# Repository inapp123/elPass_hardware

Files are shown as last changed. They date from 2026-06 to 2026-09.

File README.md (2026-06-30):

# ePass EL or elPass

**An open-source EL display controller built on the Xilinx Zynq-7010.**

ePass EL drives an electroluminescent (EL) panel from a Zynq-7010 SoC, pairing
PS-side Linux with PL-side panel timing so you get a real compositor on top of a
display technology that usually only sees bit-banged microcontroller drivers.
HDMI in/out, WiFi/BT, USB host, a resistive touchscreen, and USB-C PD power all
live on a single self-designed four-layer board.

> Rhodes Island Engineering Dept. (c) 1097 — *because every ruler needs a screen.*

---

## Status

| Subsystem | State |
| --- | --- |
| PCB (4-layer) | **Fabricated and bring-up tested.** Working hardware. |
| FPGA / Linux | Architecture defined; EL driver + DRM compositor in progress |
| Enclosure | 2-piece FDM/resin shell, parametric (build123d), in design |

This is `Rev 1`. KiCad 10.0.3 source, schematic dated 2026-05-25.

PCB is designed for JLC04016-3313 stack.1.6mm,3313 imdepend matching.

---

## Highlights

- **Zynq-7010 (CLG400)** — dual-core Cortex-A9 PS + Artix-class PL on one die.
- **EL panel driver in the PL** — column/row drive (`UD*`/`LD*`/`CP*`/`S`) with
  1-bit temporal dithering, level-shifted to the panel through dual TXS0108E.
- **DRM/KMS on Linux** — a single-master compositor owns the CRTC; clients hand
  in buffers over dmabuf. Legacy fbdev programs and even an X server can run as
  clients without ever touching the real DRM master.
- **HDMI, both directions** — J2 is a dual-mode sink/source. Default build is a
  sink (TMDS receive into HR banks via IDELAY/ISERDES); populate `D2` to flip it
  into a source.
- **WiFi + Bluetooth** — RTL8723BS over SDIO (routed through EMIO to the PL),
  with a 2.4 GHz chip antenna and a proper RF keepout.
- **USB-C PD power** — CH224K negotiates 12 V for the panel rail; data lines
  stay free for whatever you want.
- **USB 2.0 host** — USB3320 ULPI PHY (24 MHz) to a full-size Type-A port.
- **Resistive touch** — XPT2046 over SPI.
- **microSD** boot + storage, RTC-less but with the usual JTAG/UART debug paths.

---

## Architecture

```mermaid
flowchart TB
    USBC[USB-C In<br/>CH224K PD sink] --> PWR
    PWR[EA3059 quad buck<br/>+ TPS563201] -->|1V0 / 1V8 / 1V35 / 3V3 / 5V / 12V| ZYNQ

    subgraph ZYNQ[Zynq-7010]
        PS[PS<br/>Cortex-A9 + Linux]
        PL[PL<br/>EL timing + dither<br/>HDMI TMDS]
    end

    PS <-->|EMIO SDIO| WIFI[RTL8723BS<br/>WiFi/BT]
    PS --> USB[USB3320 ULPI] --> USBA[USB-A Host]
    PS --> SD[microSD]
    PS <-->|DDR| DDR[MT41K256M16<br/>512 MB DDR3L]

    PL -->|level shift| EL[EL Panel]
    PL <--> HDMI[HDMI A<br/>sink / source]
    PS -->|SPI| TOUCH[XPT2046<br/>resistive touch]
```

### PS / PL split

- **PS** runs Linux and owns the slow-and-smart side: USB, SD, the RTL8723BS
  (SDIO bridged out through EMIO to PL pins), DDR3L, and the touch SPI link.
- **PL** owns the timing-critical side: generating EL panel drive waveforms with
  1-bit dithering, and the HDMI TMDS datapath.

---

## Power tree

USB-C comes in, CH224K trips the source to **12 V**, and everything fans out from
there. The Zynq rails are brought up in the order the datasheet asks for.

| Rail | Source | Notes |
| --- | --- | --- |
| +5 V | TPS563201 | Buck from VBUS |
| +1.0 V | EA3059 | `VCCINT` / `VCCPINT` |
| +1.8 V | EA3059 | `VCCAUX` / `VCCPAUX` / MIO bank 1 |
| +1.35 V| EA3059 | DDR3L `VCCO_DDR` |
| +3.3 V | EA3059 | I/O banks, MIO bank 0, last to rise |

**Sequence:** `1.0 V → 1.8 V → 1.35 V → 3.3 V`
(approx. instant → 22 ms → 41 ms → 55 ms, set by the enable-cap timing).
A **MAX811** supervises the last-rising 3.3 V rail and drives `PS_POR_B`.

**Panel budget:** 5 V @ 300 mA max, 12 V @ 1.3 A max.

---

## Boot configuration

Mode straps live on the MIO pins (see `zynq_misc`):

| Pins | Value | Meaning |
| --- | --- | --- |
| MIO[6] | `0` | Wait for PLL lock, then run BootROM |
| MIO[8:7]  | `2'b10` | 3.3 V on both MIO banks |
| MIO[5:3]  | `3'b110` | Boot from SD card |
| MIO[2] | `0` | JTAG chain: cascaded |

PS reference clock is a 50 MHz oscillator. JTAG is broken out on a ZX-SH1.0
header for bring-up.

---

## Software stack

The interesting part isn't that it runs Linux — it's *how the display is shared.*

- **Single-master DRM compositor.** A DRM lease can't split a CRTC between two
  masters, so one compositor owns all atomic commits. Clients submit buffers as
  dmabuf file descriptors passed over a Unix socket (`SCM_RIGHTS`).
- **Legacy fbdev support** via `LD_PRELOAD`, intercepting `open`/`ioctl`/`mmap`
  so old framebuffer programs think they own a screen.
- **X11 as a client** — `xf86-video-fbdev` runs against the compositor's virtual
  framebuffer, keeping the compositor as the sole DRM master.
- **Touch routing.** The real input device is grabbed (`EVIOCGRAB`) and a virtual
  device is published via `uinput`/`libevdev`; the compositor routes events by
  overlay visibility. On focus switch, in-flight multitouch slots are cancelled
  cleanly (`ABS_MT_TRACKING_ID = -1`, `BTN_TOUCH = 0`, `SYN_REPORT`). A udev rule
  (`LIBINPUT_IGNORE_DEVICE=1`) hides the raw device from X's libinput.

## Credits

This design stands on the shoulders of:

- **ZYNQ_Ruler** by Stanlazy — <https://github.com/Stanlazy/ZYNQ_Ruler>
- **Enchanter** by Modos Tech / Wenting Zhang
- **EBAZ4205** community reverse-engineering work

Thanks to everyone who documented Zynq-7010 minimal designs and EL driving so the
rest of us didn't have to start from a blank schematic.

---

## License

CERN-OHL-P.

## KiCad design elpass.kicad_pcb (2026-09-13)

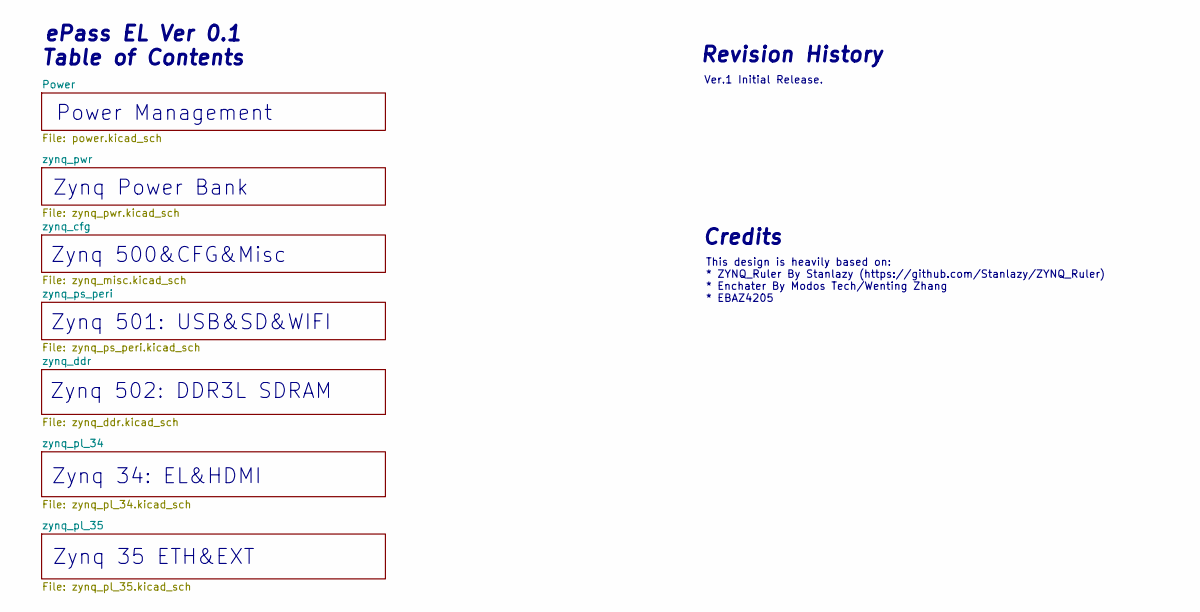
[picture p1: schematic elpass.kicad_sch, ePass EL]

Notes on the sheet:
Zynq Power Bank
Zynq 502: DDR3L SDRAM
Zynq 35 ETH&EXT
ePass EL Ver 0.1 Table of Contents
Power Management
Credits
Zynq 500&CFG&Misc
Zynq 34: EL&HDMI
Ver.1 Initial Release.
Zynq 501: USB&SD&WIFI
This design is heavily based on: * ZYNQ_Ruler By Stanlazy (https://github.com/Stanlazy/ZYNQ_Ruler) * Enchater By Modos Tech/Wenting Zhang * EBAZ4205
Revision History

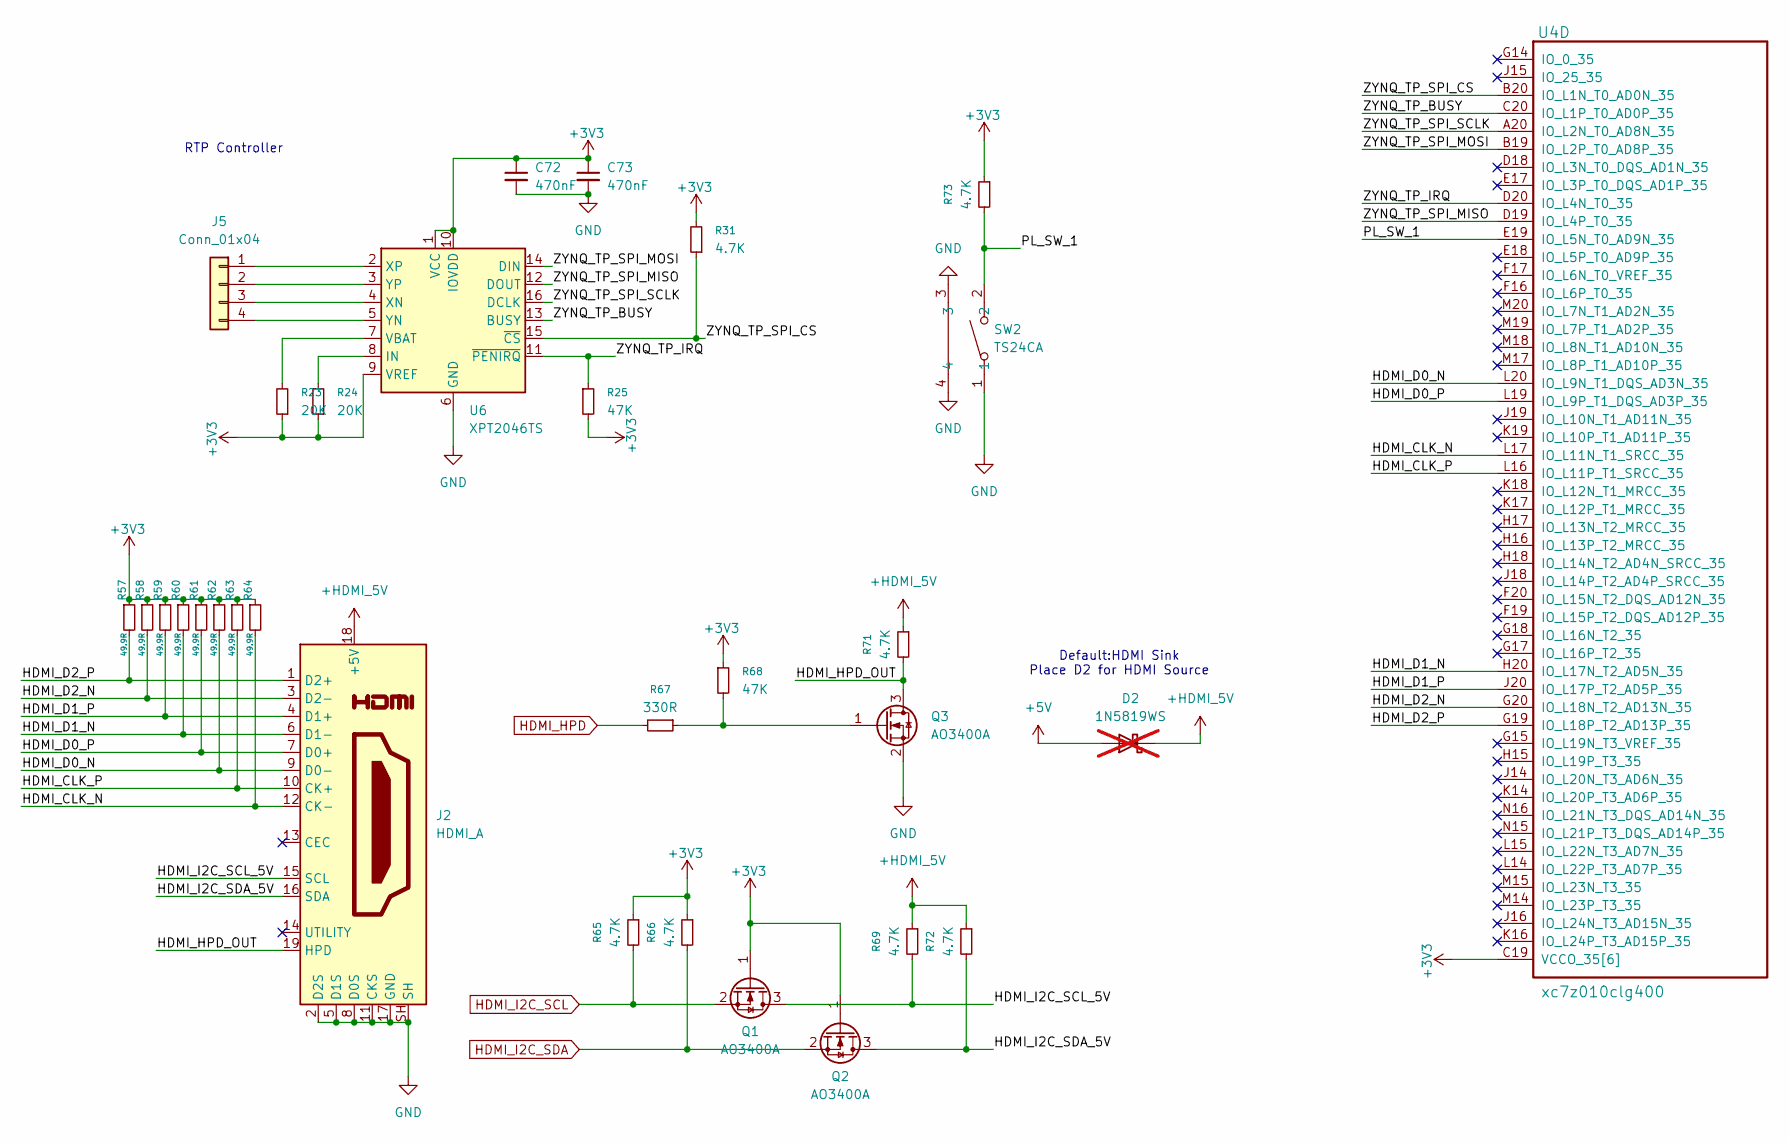
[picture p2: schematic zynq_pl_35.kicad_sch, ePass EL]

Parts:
C72, C73: 470nF; C_0201_0603Metric
D2: 1N5819WS; D_SOD-323; not fitted
J2: HDMI_A; HDMI_A_Molex_208658-1001_Horizontal
J5: Conn_01x04; PinHeader_1x04_P2.54mm_Horizontal
Q1, Q2, Q3: AO3400A; SOT-23
R23, R24: 20K; R_0402_1005Metric
R25, R68: 47K; R_0402_1005Metric
R31, R65, R66, R69, R71, R72, R73: 4.7K; R_0402_1005Metric
R57, R58, R59, R60, R61, R62, R63, R64: 49.9R; R_0402_1005Metric
R67: 330R; R_0402_1005Metric
SW2: TS24CA; SW-SMD_2P-TS24CA; MPN TS24CA; LCSC Part C393942
U4: xc7z010clg400; Xilinx_CLG400_NoPaste_JLC_Package_Delay
U6: XPT2046TS; TSSOP-16_4.4x5mm_P0.65mm

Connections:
+3V3: C72.1, C73.1, Q1.1 (G), Q2.1 (G), R23.1, R24.1, R25.2, R31.2, R57.1, R58.1, R59.1, R60.1, R61.1, R62.1, R63.1, R64.1, R65.1, R66.1, R68.1, R73.1, U4.C19 (VCCO_35[6]), U4.F18 (VCCO_35[6]), U4.H14 (VCCO_35[6]), U4.J17 (VCCO_35[6]), U4.K20 (VCCO_35[6]), U4.M16 (VCCO_35[6]), U6.1 (VCC), U6.9 (VREF), U6.10 (IOVDD); also elsewhere on the board
+5V: D2.2 (A); also elsewhere on the board
+HDMI_5V: D2.1 (K), J2.18 (+5V), R69.1, R71.1, R72.1
/zynq_pl_35/HDMI_CLK_N: J2.12 (CK-), R64.2, U4.L17 (IO_L11N_T1_SRCC_35)
/zynq_pl_35/HDMI_CLK_P: J2.10 (CK+), R63.2, U4.L16 (IO_L11P_T1_SRCC_35)
/zynq_pl_35/HDMI_D0_N: J2.9 (D0-), R62.2, U4.L20 (IO_L9N_T1_DQS_AD3N_35)
/zynq_pl_35/HDMI_D0_P: J2.7 (D0+), R61.2, U4.L19 (IO_L9P_T1_DQS_AD3P_35)
/zynq_pl_35/HDMI_D1_N: J2.6 (D1-), R60.2, U4.H20 (IO_L17N_T2_AD5N_35)
/zynq_pl_35/HDMI_D1_P: J2.4 (D1+), R59.2, U4.J20 (IO_L17P_T2_AD5P_35)
/zynq_pl_35/HDMI_D2_N: J2.3 (D2-), R58.2, U4.G20 (IO_L18N_T2_AD13N_35)
/zynq_pl_35/HDMI_D2_P: J2.1 (D2+), R57.2, U4.G19 (IO_L18P_T2_AD13P_35)
/zynq_pl_35/HDMI_HPD_OUT: J2.19 (HPD), Q3.3 (D), R71.2
/zynq_pl_35/HDMI_I2C_SCL_5V: J2.15 (SCL), Q1.3 (D), R69.2
/zynq_pl_35/HDMI_I2C_SDA_5V: J2.16 (SDA), Q2.3 (D), R72.2
/zynq_pl_35/PL_SW_1: R73.2, SW2.2, U4.E19 (IO_L5N_T0_AD9N_35)
/zynq_pl_35/ZYNQ_TP_BUSY: U4.C20 (IO_L1P_T0_AD0P_35), U6.13 (BUSY)
/zynq_pl_35/ZYNQ_TP_IRQ: R25.1, U4.D20 (IO_L4N_T0_35), U6.11 (~PENIRQ)
/zynq_pl_35/ZYNQ_TP_SPI_CS: R31.1, U4.B20 (IO_L1N_T0_AD0N_35), U6.15 (~CS)
/zynq_pl_35/ZYNQ_TP_SPI_MISO: U4.D19 (IO_L4P_T0_35), U6.12 (DOUT)
/zynq_pl_35/ZYNQ_TP_SPI_MOSI: U4.B19 (IO_L2P_T0_AD8P_35), U6.14 (DIN)
/zynq_pl_35/ZYNQ_TP_SPI_SCLK: U4.A20 (IO_L2N_T0_AD8N_35), U6.16 (DCLK)
GND: C72.2, C73.2, J2.2 (D2S), J2.5 (D1S), J2.8 (D0S), J2.11 (CKS), J2.17 (GND), J2.SH, Q3.2 (S), SW2.1, SW2.3, SW2.4, U6.6 (GND); also elsewhere on the board
HDMI_HPD: R67.2; also elsewhere on the board
HDMI_I2C_SCL: Q1.2 (S), R65.2; also elsewhere on the board
HDMI_I2C_SDA: Q2.2 (S), R66.2; also elsewhere on the board
unnamed: J5.1, U6.2 (XP)
unnamed: J5.2, U6.3 (YP)
unnamed: J5.3, U6.4 (XN)
unnamed: J5.4, U6.5 (YN)
unnamed: Q3.1 (G), R67.1, R68.2
unnamed: R24.2, U6.8 (IN)
unnamed: R23.2, U6.7 (VBAT)

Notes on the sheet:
Default:HDMI Sink Place D2 for HDMI Source
RTP Controller

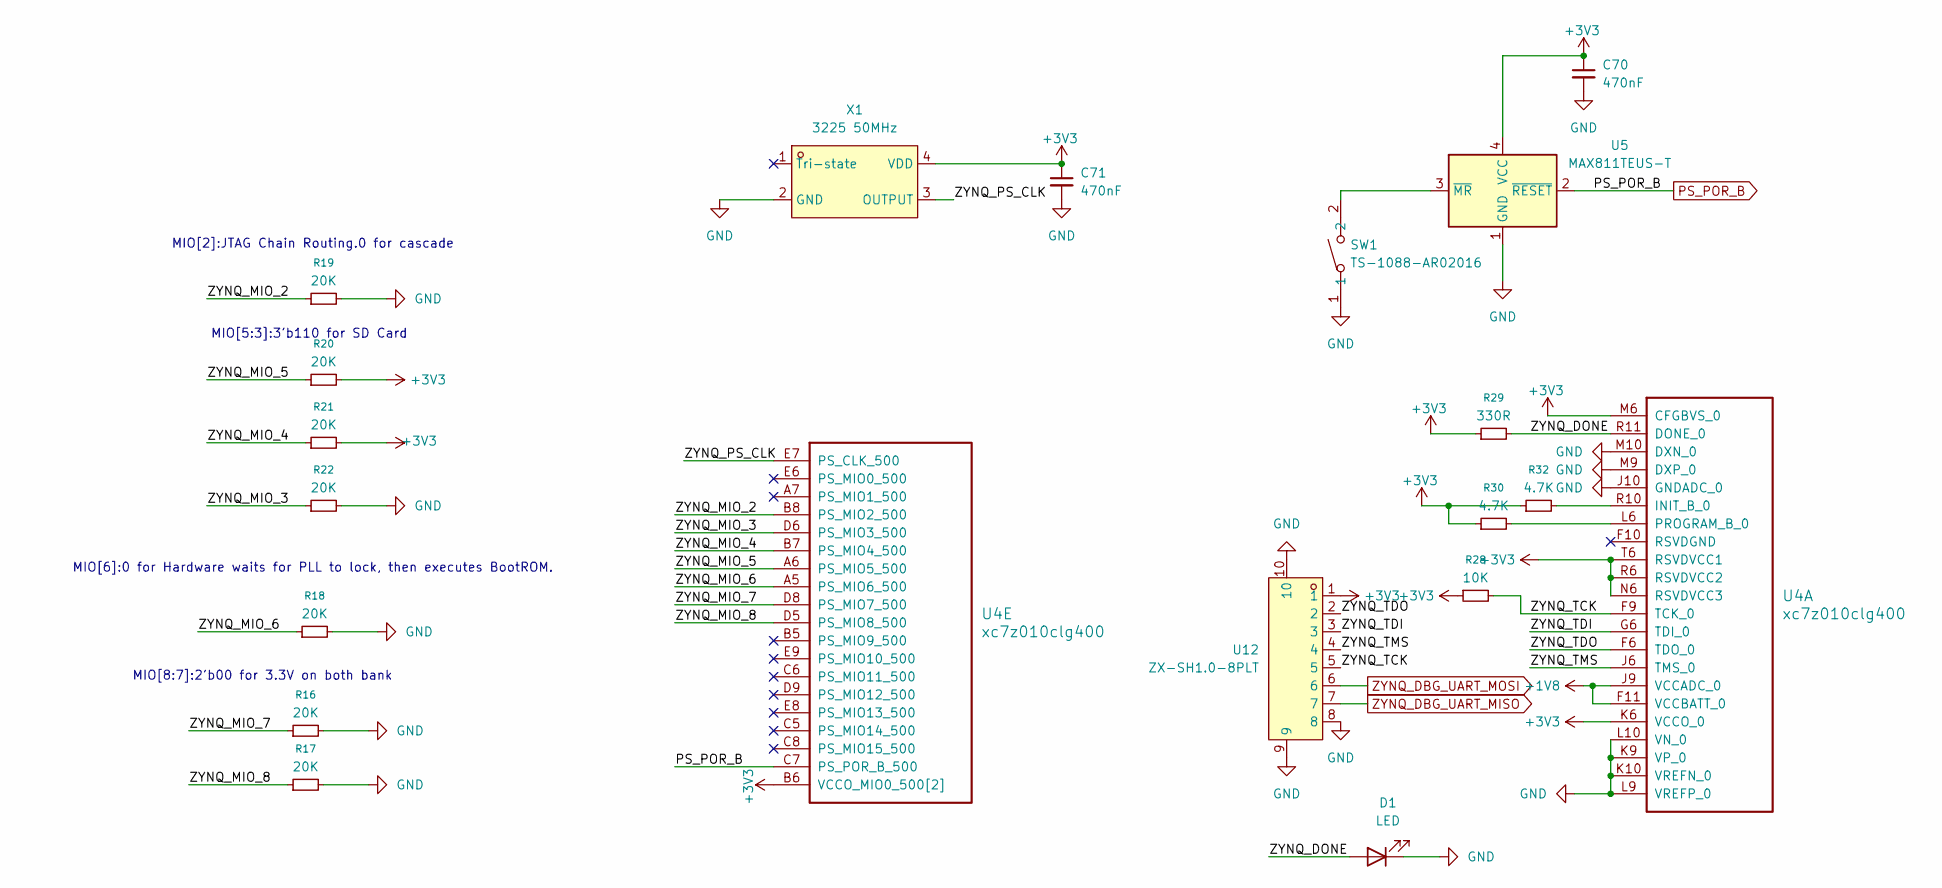
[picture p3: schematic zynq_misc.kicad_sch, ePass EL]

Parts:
C70, C71: 470nF; C_0201_0603Metric
D1: LED; LED_0603_1608Metric
R16, R17, R18, R19, R20, R21, R22: 20K; R_0402_1005Metric
R28: 10K; R_0402_1005Metric
R29: 330R; R_0402_1005Metric
R30, R32: 4.7K; R_0402_1005Metric
SW1: TS-1088-AR02016; SW-SMD_L3.9-W3.0-P4.45; MPN TS-1088-AR02016; LCSC Part C720477
U4: xc7z010clg400; Xilinx_CLG400_NoPaste_JLC_Package_Delay
U5: MAX811TEUS-T; SOT-143
U12: ZX-SH1.0-8PLT; CONN-SMD_8P-P1.00_MEGASTAR_ZX-SH1.0-8PLT; MPN ZX-SH1.0-8PLT; LCSC Part C7430457
X1: 3225 50MHz; OSC-SMD_4P-L3.2-W2.5-BL; MPN OT322550MJBA4SL; LCSC Part C717684

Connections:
+1V8: U4.F11 (VCCBATT_0), U4.J9 (VCCADC_0); also elsewhere on the board
+3V3: C70.1, C71.1, R20.2, R21.2, R28.1, R29.1, R30.1, R32.1, U4.B6 (VCCO_MIO0_500[2]), U4.D7 (VCCO_MIO0_500[2]), U4.K6 (VCCO_0), U4.M6 (CFGBVS_0), U4.N6 (RSVDVCC3), U4.R6 (RSVDVCC2), U4.T6 (RSVDVCC1), U5.4 (VCC), U12.1, X1.4 (VDD); also elsewhere on the board
/zynq_cfg/ZYNQ_DONE: D1.2 (A), R29.2, U4.R11 (DONE_0)
/zynq_cfg/ZYNQ_MIO_2: R19.1, U4.B8 (PS_MIO2_500)
/zynq_cfg/ZYNQ_MIO_3: R22.1, U4.D6 (PS_MIO3_500)
/zynq_cfg/ZYNQ_MIO_4: R21.1, U4.B7 (PS_MIO4_500)
/zynq_cfg/ZYNQ_MIO_5: R20.1, U4.A6 (PS_MIO5_500)
/zynq_cfg/ZYNQ_MIO_6: R18.1, U4.A5 (PS_MIO6_500)
/zynq_cfg/ZYNQ_MIO_7: R16.1, U4.D8 (PS_MIO7_500)
/zynq_cfg/ZYNQ_MIO_8: R17.1, U4.D5 (PS_MIO8_500)
/zynq_cfg/ZYNQ_PS_CLK: U4.E7 (PS_CLK_500), X1.3 (OUTPUT)
/zynq_cfg/ZYNQ_TCK: R28.2, U4.F9 (TCK_0), U12.5
/zynq_cfg/ZYNQ_TDI: U4.G6 (TDI_0), U12.3
/zynq_cfg/ZYNQ_TDO: U4.F6 (TDO_0), U12.2
/zynq_cfg/ZYNQ_TMS: U4.J6 (TMS_0), U12.4
GND: C70.2, C71.2, D1.1 (K), R16.2, R17.2, R18.2, R19.2, R22.2, SW1.1, U4.J10 (GNDADC_0), U4.K9 (VP_0), U4.K10 (VREFN_0), U4.L9 (VREFP_0), U4.L10 (VN_0), U4.M9 (DXP_0), U4.M10 (DXN_0), U5.1 (GND), U12.8, U12.9, U12.10, X1.2 (GND); also elsewhere on the board
unnamed: R32.2, U4.R10 (INIT_B_0)
unnamed: R30.2, U4.L6 (PROGRAM_B_0)
unnamed: SW1.2, U5.3 (~MR)
PS_POR_B: U4.C7 (PS_POR_B_500), U5.2 (~RESET)
ZYNQ_DBG_UART_MISO: U12.7; also elsewhere on the board
ZYNQ_DBG_UART_MOSI: U12.6; also elsewhere on the board

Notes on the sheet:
MIO[5:3]:3'b110 for SD Card
MIO[8:7]:2'b00 for 3.3V on both bank
MIO[2]:JTAG Chain Routing.0 for cascade
MIO[6]:0 for Hardware waits for PLL to lock, then executes BootROM.

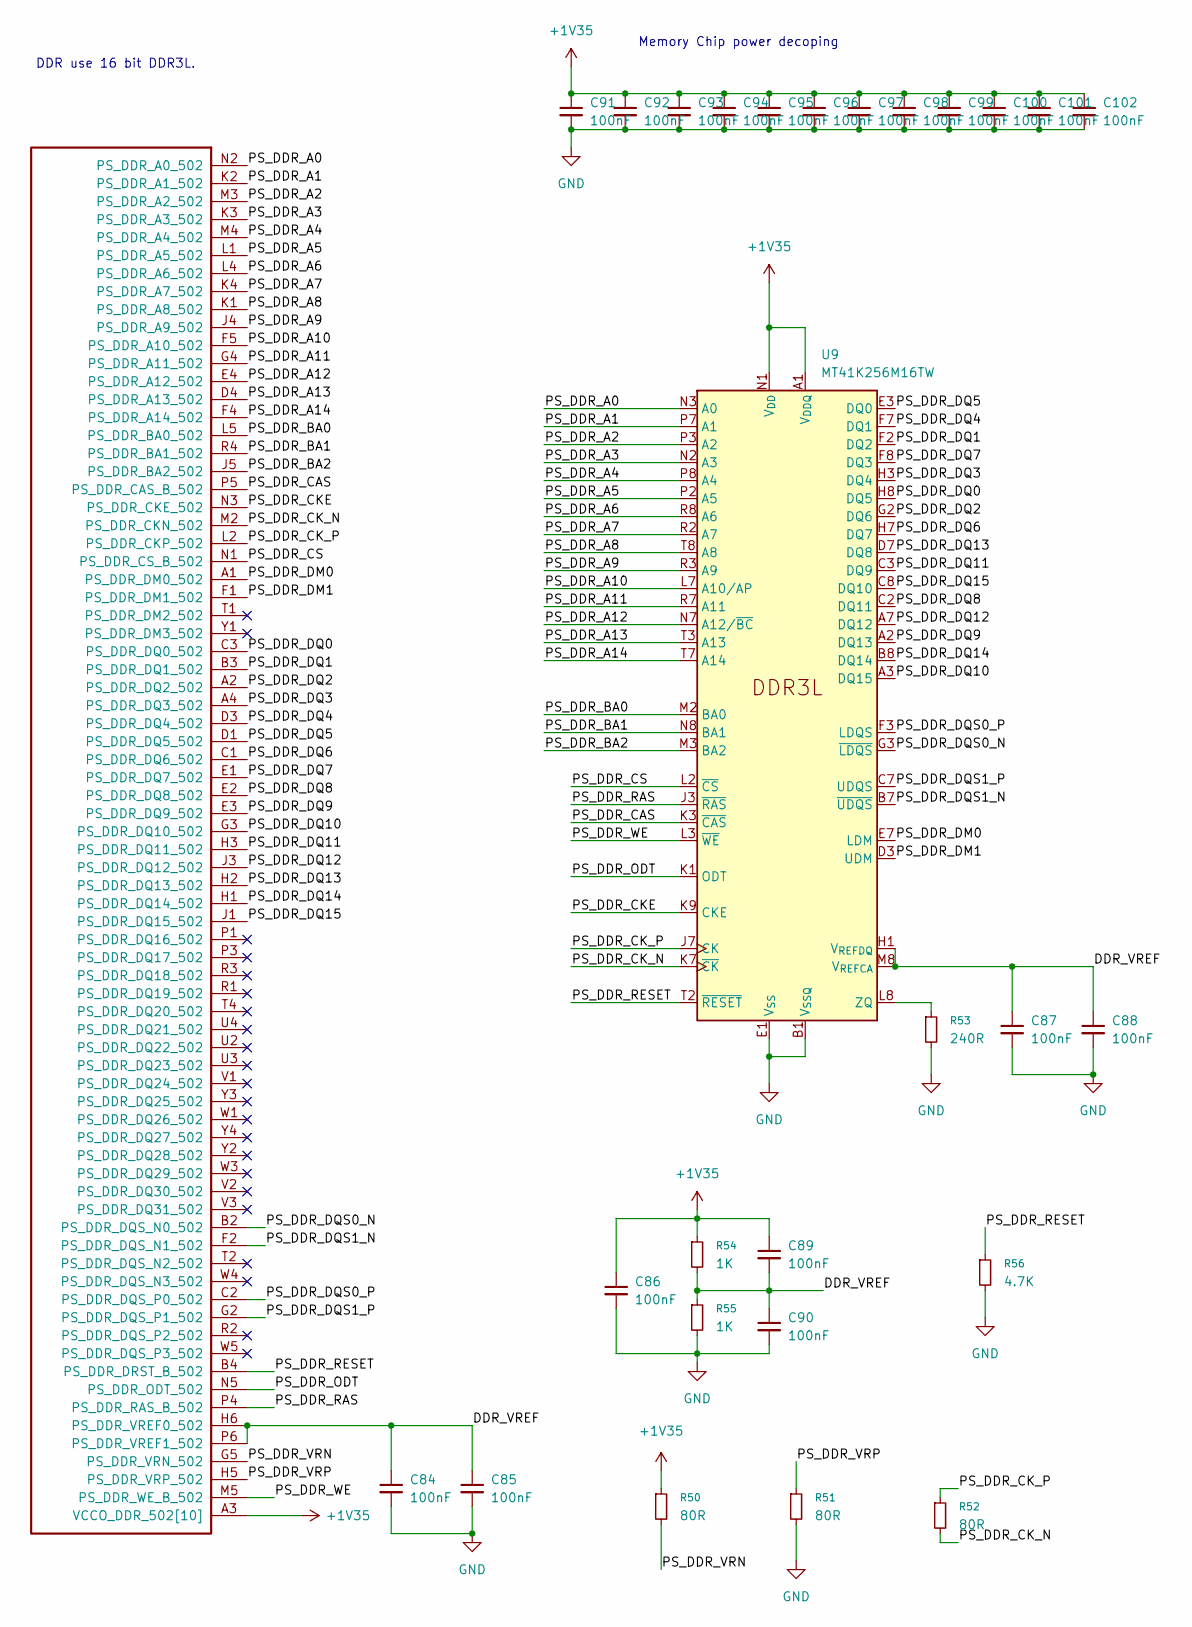
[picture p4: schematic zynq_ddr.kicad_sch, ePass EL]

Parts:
C84, C86, C87, C88, C89, C90, C91, C92, C93, C94, C95, C98, C99, C100, C101, C102: 100nF; C_0201_0603Metric
C85, C96, C97: 100nF; C_0201_0603Metric_WideGap
R50, R51: 80R; R_0201_0603Metric
R52: 80R; C_0201_0603Metric_WideGap
R53: 240R; R_0201_0603Metric
R54, R55: 1K; R_0402_1005Metric
R56: 4.7K; R_0402_1005Metric
U4: xc7z010clg400; Xilinx_CLG400_NoPaste_JLC_Package_Delay
U9: MT41K256M16TW; BGA-96_P0.8mm_NoPaste

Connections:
+1V35: C86.1, C89.1, C91.1, C92.1, C93.1, C94.1, C95.1, C96.1, C97.1, C98.1, C99.1, C100.1, C101.1, C102.1, R50.1, R54.1, U4.A3 (VCCO_DDR_502[10]), U4.D2 (VCCO_DDR_502[10]), U4.E5 (VCCO_DDR_502[10]), U4.G1 (VCCO_DDR_502[10]), U4.H4 (VCCO_DDR_502[10]), U4.L3 (VCCO_DDR_502[10]), U4.P2 (VCCO_DDR_502[10]), U4.R5 (VCCO_DDR_502[10]), U4.U1 (VCCO_DDR_502[10]), U4.V4 (VCCO_DDR_502[10]), U9.A1 (V_{DDQ}), U9.A8 (V_{DDQ}), U9.B2 (V_{DD}), U9.C1 (V_{DDQ}), U9.C9 (V_{DDQ}), U9.D2 (V_{DDQ}), U9.D9 (V_{DD}), U9.E9 (V_{DDQ}), U9.F1 (V_{DDQ}), U9.G7 (V_{DD}), U9.H2 (V_{DDQ}), U9.H9 (V_{DDQ}), U9.K2 (V_{DD}), U9.K8 (V_{DD}), U9.N1 (V_{DD}), U9.N9 (V_{DD}), U9.R1 (V_{DD}), U9.R9 (V_{DD}); also elsewhere on the board
/zynq_ddr/DDR_VREF: C84.1, C85.1, C87.1, C88.1, C89.2, C90.1, R54.2, R55.1, U4.H6 (PS_DDR_VREF0_502), U4.P6 (PS_DDR_VREF1_502), U9.H1 (V_{REFDQ}), U9.M8 (V_{REFCA})
/zynq_ddr/PS_DDR_A0: U4.N2 (PS_DDR_A0_502), U9.N3 (A0)
/zynq_ddr/PS_DDR_A1: U4.K2 (PS_DDR_A1_502), U9.P7 (A1)
/zynq_ddr/PS_DDR_A2: U4.M3 (PS_DDR_A2_502), U9.P3 (A2)
/zynq_ddr/PS_DDR_A3: U4.K3 (PS_DDR_A3_502), U9.N2 (A3)
/zynq_ddr/PS_DDR_A4: U4.M4 (PS_DDR_A4_502), U9.P8 (A4)
/zynq_ddr/PS_DDR_A5: U4.L1 (PS_DDR_A5_502), U9.P2 (A5)
/zynq_ddr/PS_DDR_A6: U4.L4 (PS_DDR_A6_502), U9.R8 (A6)
/zynq_ddr/PS_DDR_A7: U4.K4 (PS_DDR_A7_502), U9.R2 (A7)
/zynq_ddr/PS_DDR_A8: U4.K1 (PS_DDR_A8_502), U9.T8 (A8)
/zynq_ddr/PS_DDR_A9: U4.J4 (PS_DDR_A9_502), U9.R3 (A9)
/zynq_ddr/PS_DDR_A10: U4.F5 (PS_DDR_A10_502), U9.L7 (A10/AP)
/zynq_ddr/PS_DDR_A11: U4.G4 (PS_DDR_A11_502), U9.R7 (A11)
/zynq_ddr/PS_DDR_A12: U4.E4 (PS_DDR_A12_502), U9.N7 (A12/~BC)
/zynq_ddr/PS_DDR_A13: U4.D4 (PS_DDR_A13_502), U9.T3 (A13)
/zynq_ddr/PS_DDR_A14: U4.F4 (PS_DDR_A14_502), U9.T7 (A14)
/zynq_ddr/PS_DDR_BA0: U4.L5 (PS_DDR_BA0_502), U9.M2 (BA0)
/zynq_ddr/PS_DDR_BA1: U4.R4 (PS_DDR_BA1_502), U9.N8 (BA1)
/zynq_ddr/PS_DDR_BA2: U4.J5 (PS_DDR_BA2_502), U9.M3 (BA2)
/zynq_ddr/PS_DDR_CAS: U4.P5 (PS_DDR_CAS_B_502), U9.K3 (~CAS)
/zynq_ddr/PS_DDR_CKE: U4.N3 (PS_DDR_CKE_502), U9.K9 (CKE)
/zynq_ddr/PS_DDR_CK_N: R52.2, U4.M2 (PS_DDR_CKN_502), U9.K7 (~CK)
/zynq_ddr/PS_DDR_CK_P: R52.1, U4.L2 (PS_DDR_CKP_502), U9.J7 (CK)
/zynq_ddr/PS_DDR_CS: U4.N1 (PS_DDR_CS_B_502), U9.L2 (~CS)
/zynq_ddr/PS_DDR_DM0: U4.A1 (PS_DDR_DM0_502), U9.E7 (LDM)
/zynq_ddr/PS_DDR_DM1: U4.F1 (PS_DDR_DM1_502), U9.D3 (UDM)
/zynq_ddr/PS_DDR_DQ0: U4.C3 (PS_DDR_DQ0_502), U9.H8 (DQ5)
/zynq_ddr/PS_DDR_DQ1: U4.B3 (PS_DDR_DQ1_502), U9.F2 (DQ2)
/zynq_ddr/PS_DDR_DQ2: U4.A2 (PS_DDR_DQ2_502), U9.G2 (DQ6)
/zynq_ddr/PS_DDR_DQ3: U4.A4 (PS_DDR_DQ3_502), U9.H3 (DQ4)
/zynq_ddr/PS_DDR_DQ4: U4.D3 (PS_DDR_DQ4_502), U9.F7 (DQ1)
/zynq_ddr/PS_DDR_DQ5: U4.D1 (PS_DDR_DQ5_502), U9.E3 (DQ0)
/zynq_ddr/PS_DDR_DQ6: U4.C1 (PS_DDR_DQ6_502), U9.H7 (DQ7)
/zynq_ddr/PS_DDR_DQ7: U4.E1 (PS_DDR_DQ7_502), U9.F8 (DQ3)
/zynq_ddr/PS_DDR_DQ8: U4.E2 (PS_DDR_DQ8_502), U9.C2 (DQ11)
/zynq_ddr/PS_DDR_DQ9: U4.E3 (PS_DDR_DQ9_502), U9.A2 (DQ13)
/zynq_ddr/PS_DDR_DQ10: U4.G3 (PS_DDR_DQ10_502), U9.A3 (DQ15)
/zynq_ddr/PS_DDR_DQ11: U4.H3 (PS_DDR_DQ11_502), U9.C3 (DQ9)
/zynq_ddr/PS_DDR_DQ12: U4.J3 (PS_DDR_DQ12_502), U9.A7 (DQ12)
/zynq_ddr/PS_DDR_DQ13: U4.H2 (PS_DDR_DQ13_502), U9.D7 (DQ8)
/zynq_ddr/PS_DDR_DQ14: U4.H1 (PS_DDR_DQ14_502), U9.B8 (DQ14)
/zynq_ddr/PS_DDR_DQ15: U4.J1 (PS_DDR_DQ15_502), U9.C8 (DQ10)
/zynq_ddr/PS_DDR_DQS0_N: U4.B2 (PS_DDR_DQS_N0_502), U9.G3 (~LDQS)
/zynq_ddr/PS_DDR_DQS0_P: U4.C2 (PS_DDR_DQS_P0_502), U9.F3 (LDQS)
/zynq_ddr/PS_DDR_DQS1_N: U4.F2 (PS_DDR_DQS_N1_502), U9.B7 (~UDQS)
/zynq_ddr/PS_DDR_DQS1_P: U4.G2 (PS_DDR_DQS_P1_502), U9.C7 (UDQS)
/zynq_ddr/PS_DDR_ODT: U4.N5 (PS_DDR_ODT_502), U9.K1 (ODT)
/zynq_ddr/PS_DDR_RAS: U4.P4 (PS_DDR_RAS_B_502), U9.J3 (~RAS)
/zynq_ddr/PS_DDR_RESET: R56.1, U4.B4 (PS_DDR_DRST_B_502), U9.T2 (~RESET)
/zynq_ddr/PS_DDR_VRN: R50.2, U4.G5 (PS_DDR_VRN_502)
/zynq_ddr/PS_DDR_VRP: R51.1, U4.H5 (PS_DDR_VRP_502)
/zynq_ddr/PS_DDR_WE: U4.M5 (PS_DDR_WE_B_502), U9.L3 (~WE)
GND: C84.2, C85.2, C86.2, C87.2, C88.2, C90.2, C91.2, C92.2, C93.2, C94.2, C95.2, C96.2, C97.2, C98.2, C99.2, C100.2, C101.2, C102.2, R51.2, R53.2, R55.2, R56.2, U9.A9 (V_{SS}), U9.B1 (V_{SSQ}), U9.B3 (V_{SS}), U9.B9 (V_{SSQ}), U9.D1 (V_{SSQ}), U9.D8 (V_{SSQ}), U9.E1 (V_{SS}), U9.E2 (V_{SSQ}), U9.E8 (V_{SSQ}), U9.F9 (V_{SSQ}), U9.G1 (V_{SSQ}), U9.G8 (V_{SS}), U9.G9 (V_{SSQ}), U9.J2 (V_{SS}), U9.J8 (V_{SS}), U9.M1 (V_{SS}), U9.M9 (V_{SS}), U9.P1 (V_{SS}), U9.P9 (V_{SS}), U9.T1 (V_{SS}), U9.T9 (V_{SS}); also elsewhere on the board
unnamed: R53.1, U9.L8 (ZQ)

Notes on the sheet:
DDR use 16 bit DDR3L.
Memory Chip power decoping

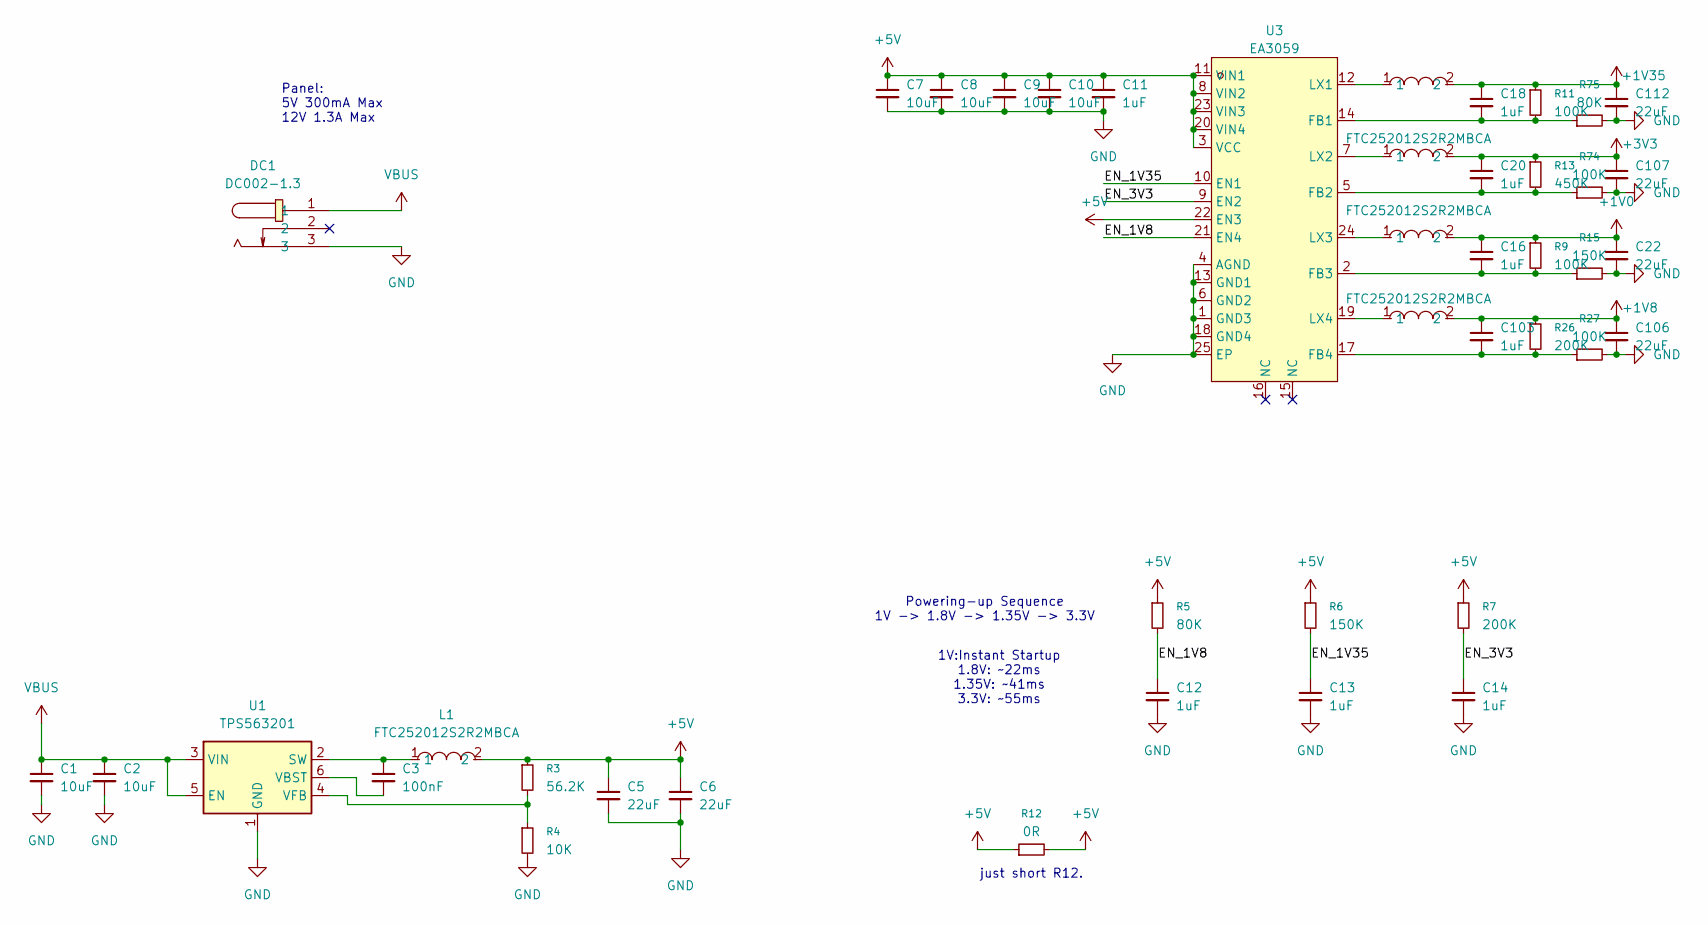
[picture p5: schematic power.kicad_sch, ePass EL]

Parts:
C1, C2, C7, C8, C9, C10: 10uF; C_0805_2012Metric
C3: 100nF; C_0201_0603Metric
C5, C6, C22, C106, C107, C112: 22uF; C_0603_1608Metric
C11, C12, C13, C14, C16, C18, C20, C103: 1uF; C_0402_1005Metric
DC1: DC002-1.3; DC-IN-TH_DC002-1.3; MPN DC002-1.3; LCSC Part C668593
L1, L3, L5, L6, L8: FTC252012S2R2MBCA; IND-SMD_L2.5-W2.0_MHCHL2520; MPN FTC252012S2R2MBCA; LCSC Part C5832372
R3: 56.2K; R_0402_1005Metric
R4: 10K; R_0402_1005Metric
R5, R75: 80K; R_0402_1005Metric
R6, R15: 150K; R_0402_1005Metric
R7, R26: 200K; R_0402_1005Metric
R9, R11, R27, R74: 100K; R_0402_1005Metric
R12: 0R; R_0805_2012Metric
R13: 450K; R_0402_1005Metric
U1: TPS563201; SOT-23-6
U3: EA3059; VQFN-24_L4.0-W4.0-P0.50-TL-EP2.5; MPN EA3059QDR; LCSC Part C111586

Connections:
+1V0: C16.1, C22.1, L3.2, R9.1; also elsewhere on the board
+1V8: C103.1, C106.1, L6.2, R26.1; also elsewhere on the board
+1V35: C18.1, C112.1, L5.2, R11.1; also elsewhere on the board
+3V3: C20.1, C107.1, L8.2, R13.1; also elsewhere on the board
+5V: C5.1, C6.1, C7.1, C8.1, C9.1, C10.1, C11.1, L1.2, R3.1, R5.1, R6.1, R7.1, R12.1, R12.2, U3.3 (VCC), U3.8 (VIN2), U3.11 (VIN1), U3.20 (VIN4), U3.22 (EN3), U3.23 (VIN3); also elsewhere on the board
/Power/EN_1V8: C12.1, R5.2, U3.21 (EN4)
/Power/EN_1V35: C13.1, R6.2, U3.10 (EN1)
/Power/EN_3V3: C14.1, R7.2, U3.9 (EN2)
GND: C1.2, C2.2, C5.2, C6.2, C7.2, C8.2, C9.2, C10.2, C11.2, C12.2, C13.2, C14.2, C22.2, C106.2, C107.2, C112.2, DC1.3, R4.2, R15.2, R27.2, R74.2, R75.2, U1.1 (GND), U3.1 (GND3), U3.4 (AGND), U3.6 (GND2), U3.13 (GND1), U3.18 (GND4), U3.25 (EP); also elsewhere on the board
unnamed: C3.1, L1.1, U1.2 (SW)
unnamed: C3.2, U1.6 (VBST)
unnamed: R3.2, R4.1, U1.4 (VFB)
unnamed: C18.2, R11.2, R75.1, U3.14 (FB1)
unnamed: C20.2, R13.2, R74.1, U3.5 (FB2)
unnamed: C16.2, R9.2, R15.1, U3.2 (FB3)
unnamed: C103.2, R26.2, R27.1, U3.17 (FB4)
unnamed: L5.1, U3.12 (LX1)
unnamed: L8.1, U3.7 (LX2)
unnamed: L3.1, U3.24 (LX3)
unnamed: L6.1, U3.19 (LX4)
VBUS: C1.1, C2.1, DC1.1, U1.3 (VIN), U1.5 (EN); also elsewhere on the board

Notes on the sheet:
Panel: 5V 300mA Max 12V 1.3A Max
just short R12.
Powering-up Sequence 1V -> 1.8V -> 1.35V -> 3.3V
1V:Instant Startup 1.8V: ~22ms 1.35V: ~41ms 3.3V: ~55ms

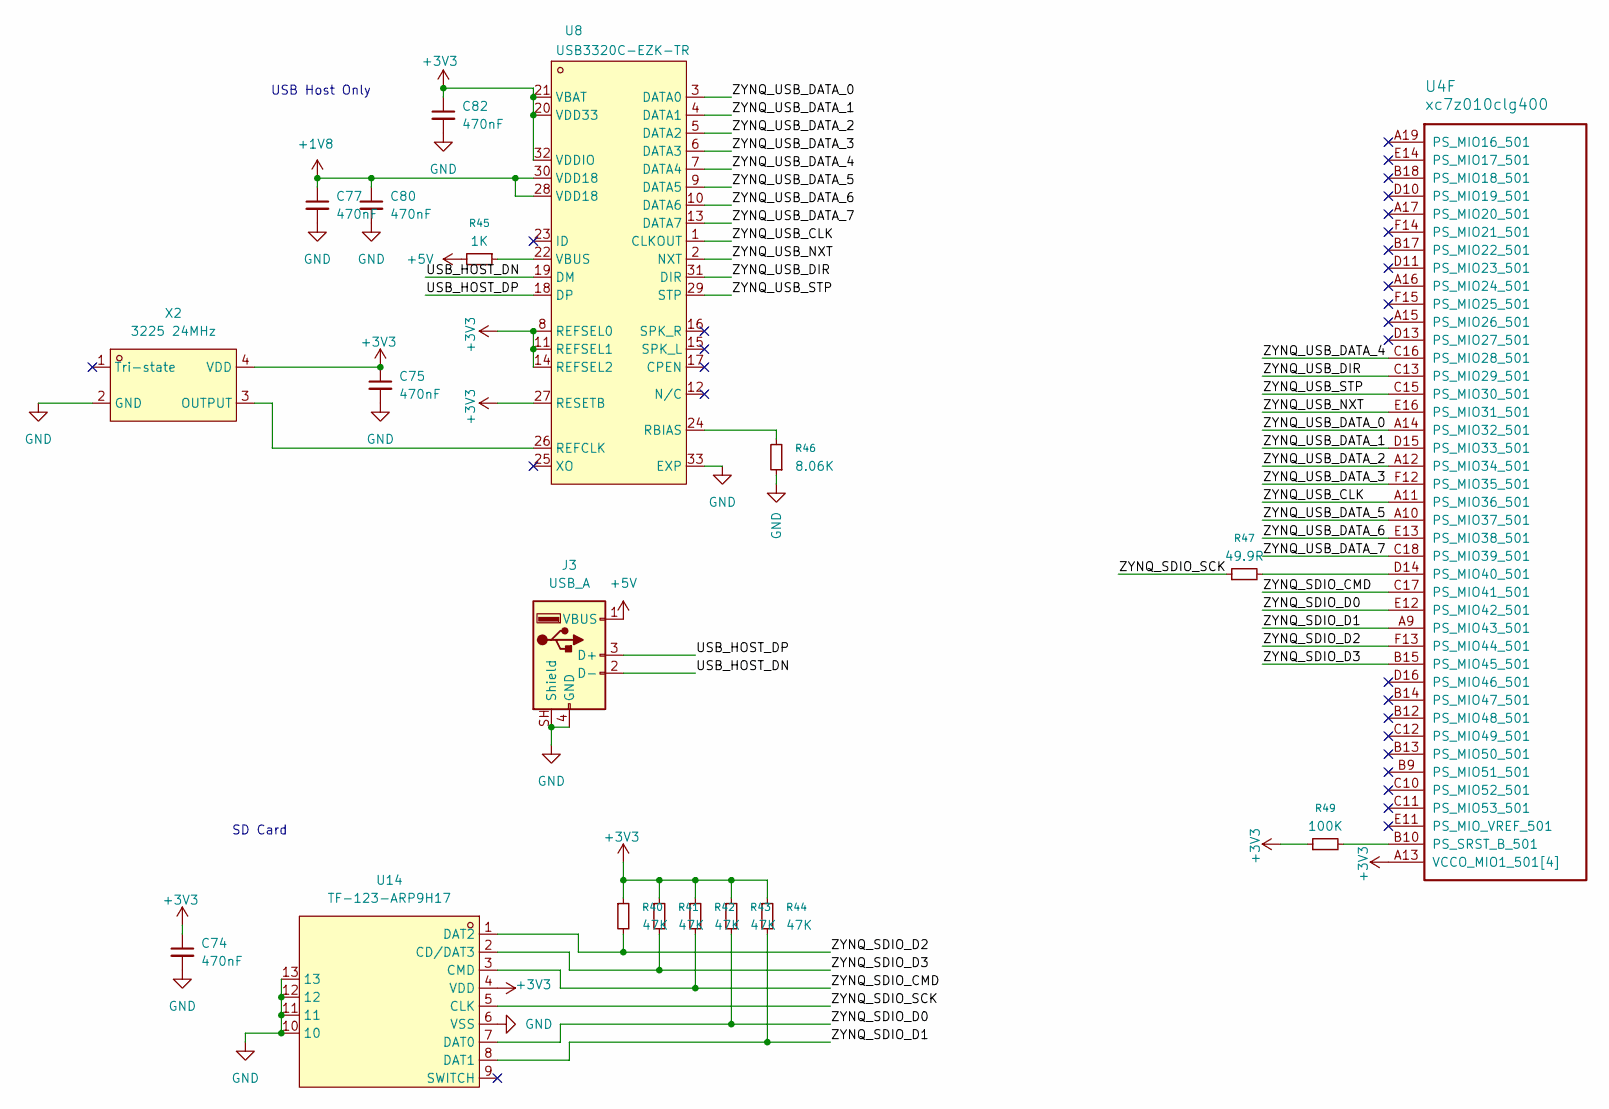
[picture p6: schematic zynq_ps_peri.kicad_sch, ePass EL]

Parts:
C74, C75, C77, C80, C82: 470nF; C_0201_0603Metric
J3: USB_A; USB_A_Molex_67643_Horizontal
R40, R41, R42, R43, R44: 47K; R_0402_1005Metric
R45: 1K; R_0402_1005Metric
R46: 8.06K; R_0402_1005Metric
R47: 49.9R; R_0402_1005Metric
R49: 100K; R_0402_1005Metric
U4: xc7z010clg400; Xilinx_CLG400_NoPaste_JLC_Package_Delay
U8: USB3320C-EZK-TR; QFN-32_L5.0-W5.0-P0.50-BL-EP3.4; MPN USB3320C-EZK-TR; LCSC Part C132156
U14: TF-123-ARP9H17; TF-SMD_TF-123-ARP9H15; MPN TF-123-ARP9H17; LCSC Part C2982548
X2: 3225 24MHz; OSC-SMD_4P-L3.2-W2.5-BL; MPN OT322550MJBA4SL; LCSC Part C717684

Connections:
+1V8: C77.1, C80.1, U8.28 (VDD18), U8.30 (VDD18); also elsewhere on the board
+3V3: C74.1, C75.1, C82.1, R40.1, R41.1, R42.1, R43.1, R44.1, R49.1, U4.A13 (VCCO_MIO1_501[4]), U4.B16 (VCCO_MIO1_501[4]), U4.D12 (VCCO_MIO1_501[4]), U4.E15 (VCCO_MIO1_501[4]), U8.8 (REFSEL0), U8.11 (REFSEL1), U8.14 (REFSEL2), U8.20 (VDD33), U8.21 (VBAT), U8.27 (RESETB), U8.32 (VDDIO), U14.4 (VDD), X2.4 (VDD); also elsewhere on the board
+5V: J3.1 (VBUS), R45.2; also elsewhere on the board
/zynq_ps_peri/USB_HOST_DN: J3.2 (D-), U8.19 (DM)
/zynq_ps_peri/USB_HOST_DP: J3.3 (D+), U8.18 (DP)
/zynq_ps_peri/ZYNQ_SDIO_CMD: R42.2, U4.C17 (PS_MIO41_501), U14.3 (CMD)
/zynq_ps_peri/ZYNQ_SDIO_D0: R43.2, U4.E12 (PS_MIO42_501), U14.7 (DAT0)
/zynq_ps_peri/ZYNQ_SDIO_D1: R44.2, U4.A9 (PS_MIO43_501), U14.8 (DAT1)
/zynq_ps_peri/ZYNQ_SDIO_D2: R40.2, U4.F13 (PS_MIO44_501), U14.1 (DAT2)
/zynq_ps_peri/ZYNQ_SDIO_D3: R41.2, U4.B15 (PS_MIO45_501), U14.2 (CD/DAT3)
/zynq_ps_peri/ZYNQ_SDIO_SCK: R47.1, U14.5 (CLK)
/zynq_ps_peri/ZYNQ_USB_CLK: U4.A11 (PS_MIO36_501), U8.1 (CLKOUT)
/zynq_ps_peri/ZYNQ_USB_DATA_0: U4.A14 (PS_MIO32_501), U8.3 (DATA0)
/zynq_ps_peri/ZYNQ_USB_DATA_1: U4.D15 (PS_MIO33_501), U8.4 (DATA1)
/zynq_ps_peri/ZYNQ_USB_DATA_2: U4.A12 (PS_MIO34_501), U8.5 (DATA2)
/zynq_ps_peri/ZYNQ_USB_DATA_3: U4.F12 (PS_MIO35_501), U8.6 (DATA3)
/zynq_ps_peri/ZYNQ_USB_DATA_4: U4.C16 (PS_MIO28_501), U8.7 (DATA4)
/zynq_ps_peri/ZYNQ_USB_DATA_5: U4.A10 (PS_MIO37_501), U8.9 (DATA5)
/zynq_ps_peri/ZYNQ_USB_DATA_6: U4.E13 (PS_MIO38_501), U8.10 (DATA6)
/zynq_ps_peri/ZYNQ_USB_DATA_7: U4.C18 (PS_MIO39_501), U8.13 (DATA7)
/zynq_ps_peri/ZYNQ_USB_DIR: U4.C13 (PS_MIO29_501), U8.31 (DIR)
/zynq_ps_peri/ZYNQ_USB_NXT: U4.E16 (PS_MIO31_501), U8.2 (NXT)
/zynq_ps_peri/ZYNQ_USB_STP: U4.C15 (PS_MIO30_501), U8.29 (STP)
GND: C74.2, C75.2, C77.2, C80.2, C82.2, J3.4 (GND), J3.SH (Shield), R46.1, U8.33 (EXP), U14.6 (VSS), U14.10, U14.11, U14.12, U14.13, X2.2 (GND); also elsewhere on the board
unnamed: R47.2, U4.D14 (PS_MIO40_501)
unnamed: R49.2, U4.B10 (PS_SRST_B_501)
unnamed: R46.2, U8.24 (RBIAS)
unnamed: U8.26 (REFCLK), X2.3 (OUTPUT)
unnamed: R45.1, U8.22 (VBUS)

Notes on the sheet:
USB Host Only
SD Card

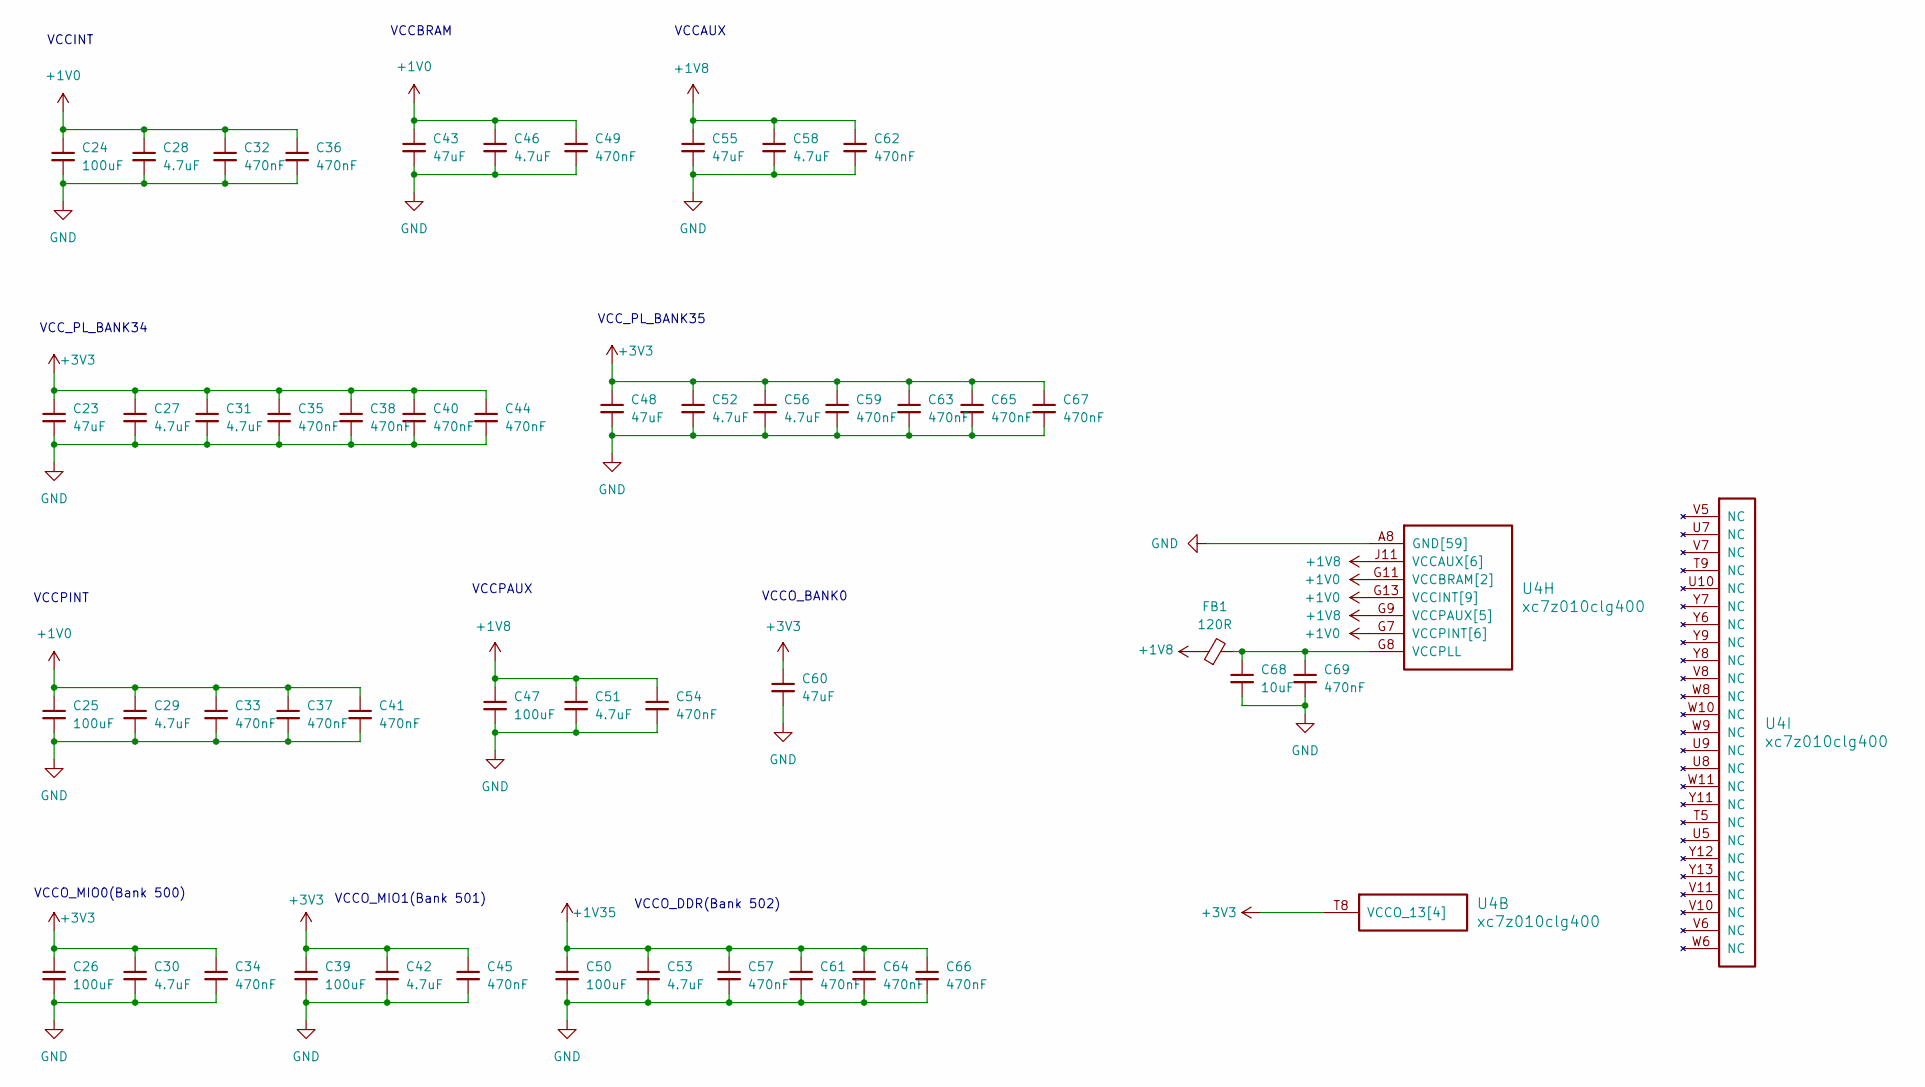
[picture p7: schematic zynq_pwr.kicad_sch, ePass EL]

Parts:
C23, C43, C48, C55, C60: 47uF; C_0603_1608Metric
C24, C25, C26, C39, C47, C50: 100uF; C_1206_3216Metric
C27, C28, C29, C30, C31, C42, C46, C51, C52, C53, C56, C58: 4.7uF; C_0402_1005Metric
C32, C33, C35, C36, C37, C38, C40, C41, C44, C45, C49, C54, C57, C59, C61, C62, C63, C64, C65, C67, C69: 470nF; C_0201_0603Metric
C34, C66: 470nF; C_0201_0603Metric_WideGap
C68: 10uF; C_0805_2012Metric
FB1: 120R; L_0603_1608Metric
U4: xc7z010clg400; Xilinx_CLG400_NoPaste_JLC_Package_Delay

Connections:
+1V0: C24.1, C25.1, C28.1, C29.1, C32.1, C33.1, C36.1, C37.1, C41.1, C43.1, C46.1, C49.1, U4.G7 (VCCPINT[6]), U4.G11 (VCCBRAM[2]), U4.G13 (VCCINT[9]), U4.H10 (VCCBRAM[2]), U4.H12 (VCCINT[9]), U4.J7 (VCCPINT[6]), U4.J13 (VCCINT[9]), U4.K12 (VCCINT[9]), U4.L7 (VCCPINT[6]), U4.L13 (VCCINT[9]), U4.M12 (VCCINT[9]), U4.N7 (VCCPINT[6]), U4.N13 (VCCINT[9]), U4.P8 (VCCPINT[6]), U4.P12 (VCCINT[9]), U4.R7 (VCCPINT[6]), U4.R13 (VCCINT[9]); also elsewhere on the board
+1V8: C47.1, C51.1, C54.1, C55.1, C58.1, C62.1, FB1.1, U4.F8 (VCCPAUX[5]), U4.G9 (VCCPAUX[5]), U4.H8 (VCCPAUX[5]), U4.J11 (VCCAUX[6]), U4.K8 (VCCPAUX[5]), U4.L11 (VCCAUX[6]), U4.M8 (VCCPAUX[5]), U4.N9 (VCCAUX[6]), U4.N11 (VCCAUX[6]), U4.P10 (VCCAUX[6]), U4.R9 (VCCAUX[6]); also elsewhere on the board
+1V35: C50.1, C53.1, C57.1, C61.1, C64.1, C66.1; also elsewhere on the board
+3V3: C23.1, C26.1, C27.1, C30.1, C31.1, C34.1, C35.1, C38.1, C39.1, C40.1, C42.1, C44.1, C45.1, C48.1, C52.1, C56.1, C59.1, C60.1, C63.1, C65.1, C67.1, U4.T8 (VCCO_13[4]), U4.U11 (VCCO_13[4]), U4.W7 (VCCO_13[4]), U4.Y10 (VCCO_13[4]); also elsewhere on the board
GND: C23.2, C24.2, C25.2, C26.2, C27.2, C28.2, C29.2, C30.2, C31.2, C32.2, C33.2, C34.2, C35.2, C36.2, C37.2, C38.2, C39.2, C40.2, C41.2, C42.2, C43.2, C44.2, C45.2, C46.2, C47.2, C48.2, C49.2, C50.2, C51.2, C52.2, C53.2, C54.2, C55.2, C56.2, C57.2, C58.2, C59.2, C60.2, C61.2, C62.2, C63.2, C64.2, C65.2, C66.2, C67.2, C68.2, C69.2, U4.A8 (GND[59]), U4.A18 (GND[59]), U4.B1 (GND[59]), U4.B11 (GND[59]), U4.C4 (GND[59]), U4.C9 (GND[59]), U4.C14 (GND[59]), U4.D17 (GND[59]), U4.E10 (GND[59]), U4.E20 (GND[59]), U4.F3 (GND[59]), U4.F7 (GND[59]), U4.G10 (GND[59]), U4.G12 (GND[59]), U4.G16 (GND[59]), U4.H7 (GND[59]), U4.H9 (GND[59]), U4.H11 (GND[59]), U4.H13 (GND[59]), U4.H19 (GND[59]), U4.J2 (GND[59]), U4.J8 (GND[59]), U4.J12 (GND[59]), U4.K5 (GND[59]), U4.K7 (GND[59]), U4.K11 (GND[59]), U4.K13 (GND[59]), U4.K15 (GND[59]), U4.L8 (GND[59]), U4.L12 (GND[59]), U4.L18 (GND[59]), U4.M1 (GND[59]), U4.M7 (GND[59]), U4.M11 (GND[59]), U4.M13 (GND[59]), U4.N4 (GND[59]), U4.N8 (GND[59]), U4.N10 (GND[59]), U4.N12 (GND[59]), U4.N14 (GND[59]), U4.P7 (GND[59]), U4.P9 (GND[59]), U4.P11 (GND[59]), U4.P13 (GND[59]), U4.P17 (GND[59]), U4.R8 (GND[59]), U4.R12 (GND[59]), U4.R20 (GND[59]), U4.T3 (GND[59]), U4.T7 (GND[59]), U4.T13 (GND[59]), U4.U6 (GND[59]), U4.U16 (GND[59]), U4.V9 (GND[59]), U4.V19 (GND[59]), U4.W2 (GND[59]), U4.W12 (GND[59]), U4.Y5 (GND[59]), U4.Y15 (GND[59]); also elsewhere on the board
unnamed: C68.1, C69.1, FB1.2, U4.G8 (VCCPLL)

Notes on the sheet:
VCCO_DDR(Bank 502)
VCCBRAM
VCC_PL_BANK34
VCCPINT
VCCINT
VCCAUX
VCCO_MIO0(Bank 500)
VCCO_BANK0
VCCPAUX
VCCO_MIO1(Bank 501)
VCC_PL_BANK35

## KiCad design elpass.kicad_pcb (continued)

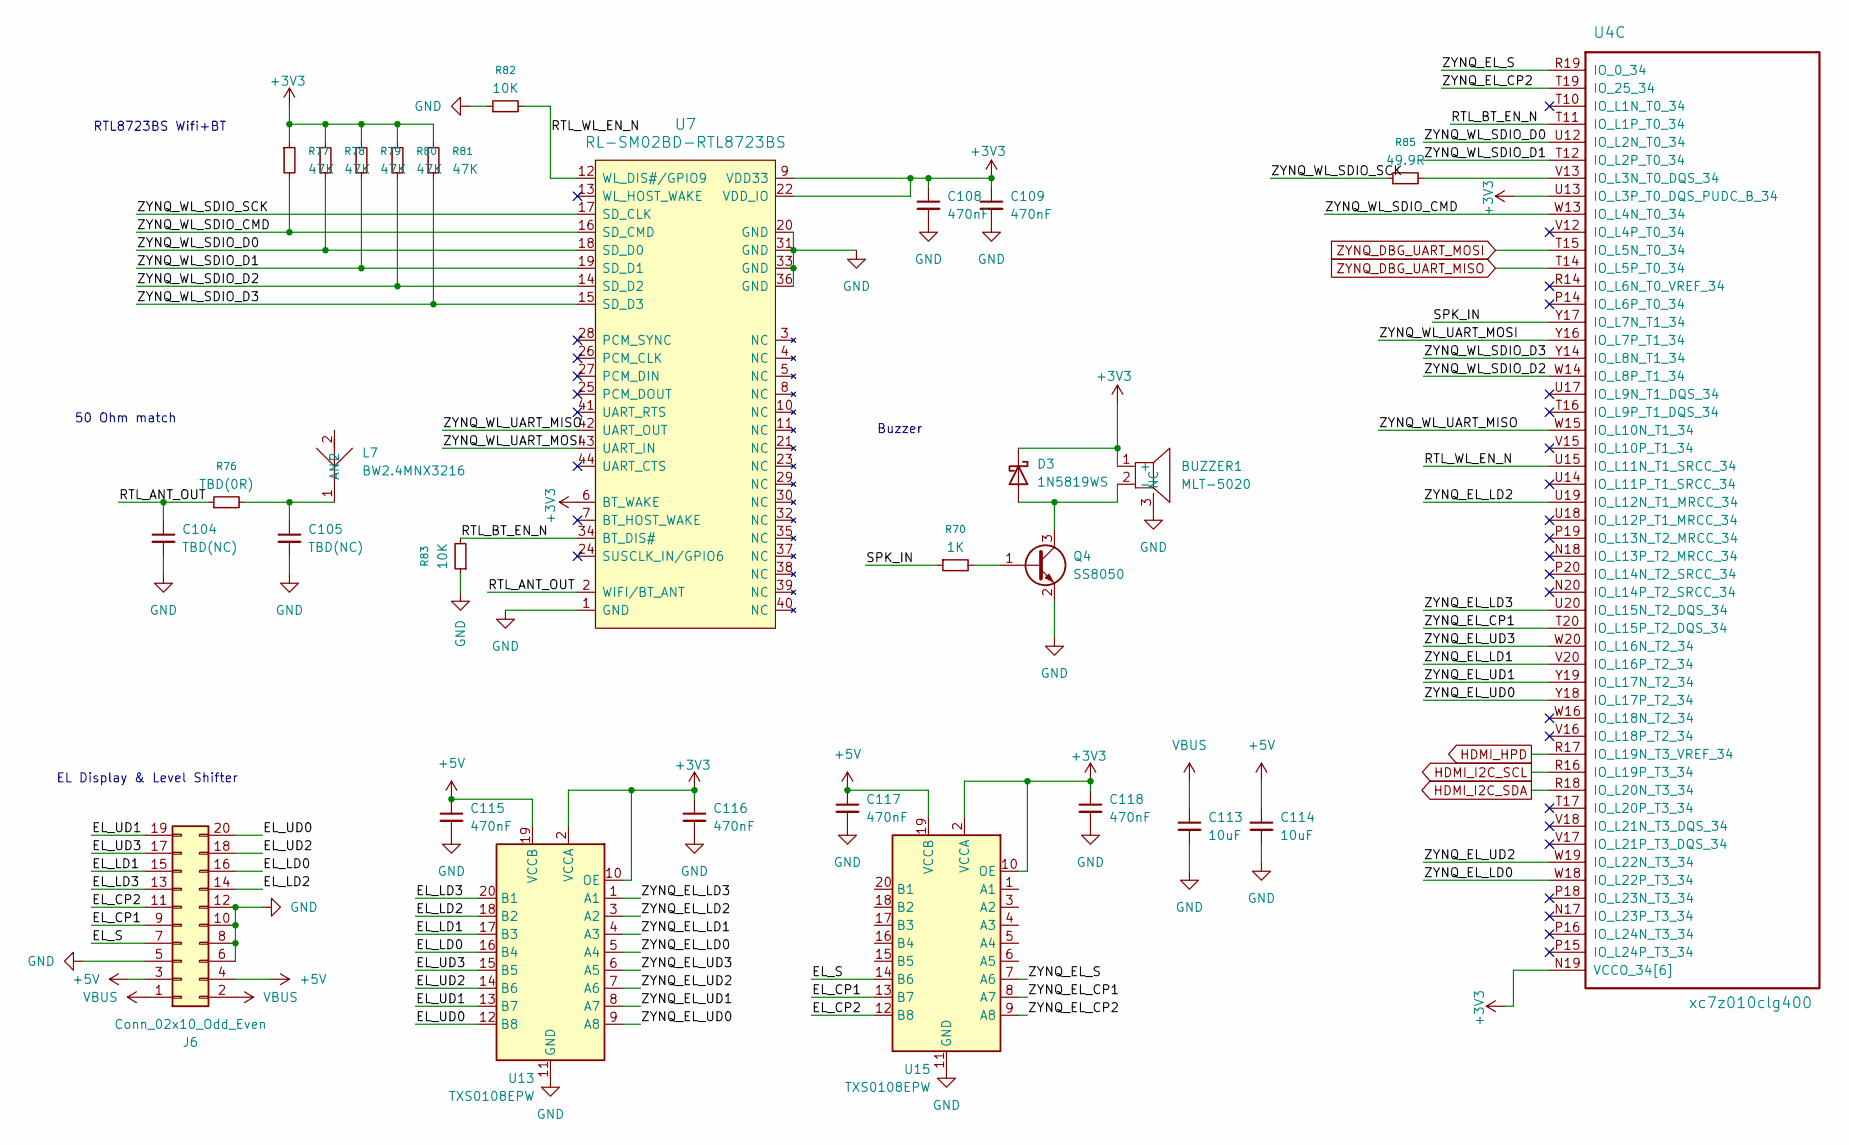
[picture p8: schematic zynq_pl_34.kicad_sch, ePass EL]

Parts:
BUZZER1: MLT-5020; BUZ-SMD_L5.0-W5.5-P4.60; MPN MLT-5020; LCSC Part C94598
C104, C105: TBD(NC); C_0402_1005Metric
C108, C109, C115, C116, C117, C118: 470nF; C_0201_0603Metric
C113, C114: 10uF; C_0805_2012Metric
D3: 1N5819WS; D_SOD-323
J6: Conn_02x10_Odd_Even; PinSocket_2x10_P2.00mm_Vertical
L7: BW2.4MNX3216; ANT-SMD_L3.4-W1.8_BW2.4MNX3216; MPN BW2.4MNX3216; LCSC Part C49330090
Q4: SS8050; SOT-23
R70: 1K; R_0402_1005Metric
R76: TBD(0R); R_0402_1005Metric
R77, R78, R79, R80, R81: 47K; R_0402_1005Metric
R82, R83: 10K; R_0402_1005Metric
R85: 49.9R; R_0402_1005Metric
U4: xc7z010clg400; Xilinx_CLG400_NoPaste_JLC_Package_Delay
U7: RL-SM02BD-RTL8723BS; WIRELM-SMD_RL-SM02BD-RTL8723BS; MPN RTL8723BS
U13, U15: TXS0108EPW; TSSOP-20_4.4x6.5mm_P0.65mm

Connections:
+3V3: BUZZER1.1 (+), C108.1, C109.1, C116.1, C118.1, D3.1 (K), R77.1, R78.1, R79.1, R80.1, R81.1, U4.N19 (VCCO_34[6]), U4.R15 (VCCO_34[6]), U4.T18 (VCCO_34[6]), U4.U13 (IO_L3P_T0_DQS_PUDC_B_34), U4.V14 (VCCO_34[6]), U4.W17 (VCCO_34[6]), U4.Y20 (VCCO_34[6]), U7.6 (BT_WAKE), U7.9 (VDD33), U7.22 (VDD_IO), U13.2 (VCCA), U13.10 (OE), U15.2 (VCCA), U15.10 (OE); also elsewhere on the board
+5V: C114.1, C115.1, C117.1, J6.3, J6.4, U13.19 (VCCB), U15.19 (VCCB); also elsewhere on the board
/zynq_pl_34/EL_CP1: J6.9, U15.13 (B7)
/zynq_pl_34/EL_CP2: J6.11, U15.12 (B8)
/zynq_pl_34/EL_LD0: J6.16, U13.16 (B4)
/zynq_pl_34/EL_LD1: J6.15, U13.17 (B3)
/zynq_pl_34/EL_LD2: J6.14, U13.18 (B2)
/zynq_pl_34/EL_LD3: J6.13, U13.20 (B1)
/zynq_pl_34/EL_S: J6.7, U15.14 (B6)
/zynq_pl_34/EL_UD0: J6.20, U13.12 (B8)
/zynq_pl_34/EL_UD1: J6.19, U13.13 (B7)
/zynq_pl_34/EL_UD2: J6.18, U13.14 (B6)
/zynq_pl_34/EL_UD3: J6.17, U13.15 (B5)
/zynq_pl_34/RTL_ANT_OUT: C104.1, R76.1, U7.2 (WIFI/BT_ANT)
/zynq_pl_34/RTL_BT_EN_N: R83.2, U4.T11 (IO_L1P_T0_34), U7.34 (BT_DIS#)
/zynq_pl_34/RTL_WL_EN_N: R82.2, U4.U15 (IO_L11N_T1_SRCC_34), U7.12 (WL_DIS#/GPIO9)
/zynq_pl_34/SPK_IN: R70.1, U4.Y17 (IO_L7N_T1_34)
/zynq_pl_34/ZYNQ_EL_CP1: U4.T20 (IO_L15P_T2_DQS_34), U15.8 (A7)
/zynq_pl_34/ZYNQ_EL_CP2: U4.T19 (IO_25_34), U15.9 (A8)
/zynq_pl_34/ZYNQ_EL_LD0: U4.W18 (IO_L22P_T3_34), U13.5 (A4)
/zynq_pl_34/ZYNQ_EL_LD1: U4.V20 (IO_L16P_T2_34), U13.4 (A3)
/zynq_pl_34/ZYNQ_EL_LD2: U4.U19 (IO_L12N_T1_MRCC_34), U13.3 (A2)
/zynq_pl_34/ZYNQ_EL_LD3: U4.U20 (IO_L15N_T2_DQS_34), U13.1 (A1)
/zynq_pl_34/ZYNQ_EL_S: U4.R19 (IO_0_34), U15.7 (A6)
/zynq_pl_34/ZYNQ_EL_UD0: U4.Y18 (IO_L17P_T2_34), U13.9 (A8)
/zynq_pl_34/ZYNQ_EL_UD1: U4.Y19 (IO_L17N_T2_34), U13.8 (A7)
/zynq_pl_34/ZYNQ_EL_UD2: U4.W19 (IO_L22N_T3_34), U13.7 (A6)
/zynq_pl_34/ZYNQ_EL_UD3: U4.W20 (IO_L16N_T2_34), U13.6 (A5)
/zynq_pl_34/ZYNQ_WL_SDIO_CMD: R77.2, U4.W13 (IO_L4N_T0_34), U7.16 (SD_CMD)
/zynq_pl_34/ZYNQ_WL_SDIO_D0: R78.2, U4.U12 (IO_L2N_T0_34), U7.18 (SD_D0)
/zynq_pl_34/ZYNQ_WL_SDIO_D1: R79.2, U4.T12 (IO_L2P_T0_34), U7.19 (SD_D1)
/zynq_pl_34/ZYNQ_WL_SDIO_D2: R80.2, U4.W14 (IO_L8P_T1_34), U7.14 (SD_D2)
/zynq_pl_34/ZYNQ_WL_SDIO_D3: R81.2, U4.Y14 (IO_L8N_T1_34), U7.15 (SD_D3)
/zynq_pl_34/ZYNQ_WL_SDIO_SCK: R85.1, U7.17 (SD_CLK)
/zynq_pl_34/ZYNQ_WL_UART_MISO: U4.W15 (IO_L10N_T1_34), U7.42 (UART_OUT)
/zynq_pl_34/ZYNQ_WL_UART_MOSI: U4.Y16 (IO_L7P_T1_34), U7.43 (UART_IN)
GND: BUZZER1.3 (NC), C104.2, C105.2, C108.2, C109.2, C113.2, C114.2, C115.2, C116.2, C117.2, C118.2, J6.5, J6.6, J6.8, J6.10, J6.12, Q4.2 (E), R82.1, R83.1, U7.1 (GND), U7.20 (GND), U7.31 (GND), U7.33 (GND), U7.36 (GND), U13.11 (GND), U15.11 (GND); also elsewhere on the board
HDMI_HPD: U4.R17 (IO_L19N_T3_VREF_34); also elsewhere on the board
HDMI_I2C_SCL: U4.R16 (IO_L19P_T3_34); also elsewhere on the board
HDMI_I2C_SDA: U4.R18 (IO_L20N_T3_34); also elsewhere on the board
unnamed: BUZZER1.2 (-), D3.2 (A), Q4.3 (C)
unnamed: C105.1, L7.1 (ANT_1), R76.2
unnamed: Q4.1 (B), R70.2
unnamed: R85.2, U4.V13 (IO_L3N_T0_DQS_34)
VBUS: C113.1, J6.1, J6.2; also elsewhere on the board
ZYNQ_DBG_UART_MISO: U4.T14 (IO_L5P_T0_34); also elsewhere on the board
ZYNQ_DBG_UART_MOSI: U4.T15 (IO_L5N_T0_34); also elsewhere on the board

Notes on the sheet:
EL Display & Level Shifter
50 Ohm match
RTL8723BS Wifi+BT
Buzzer

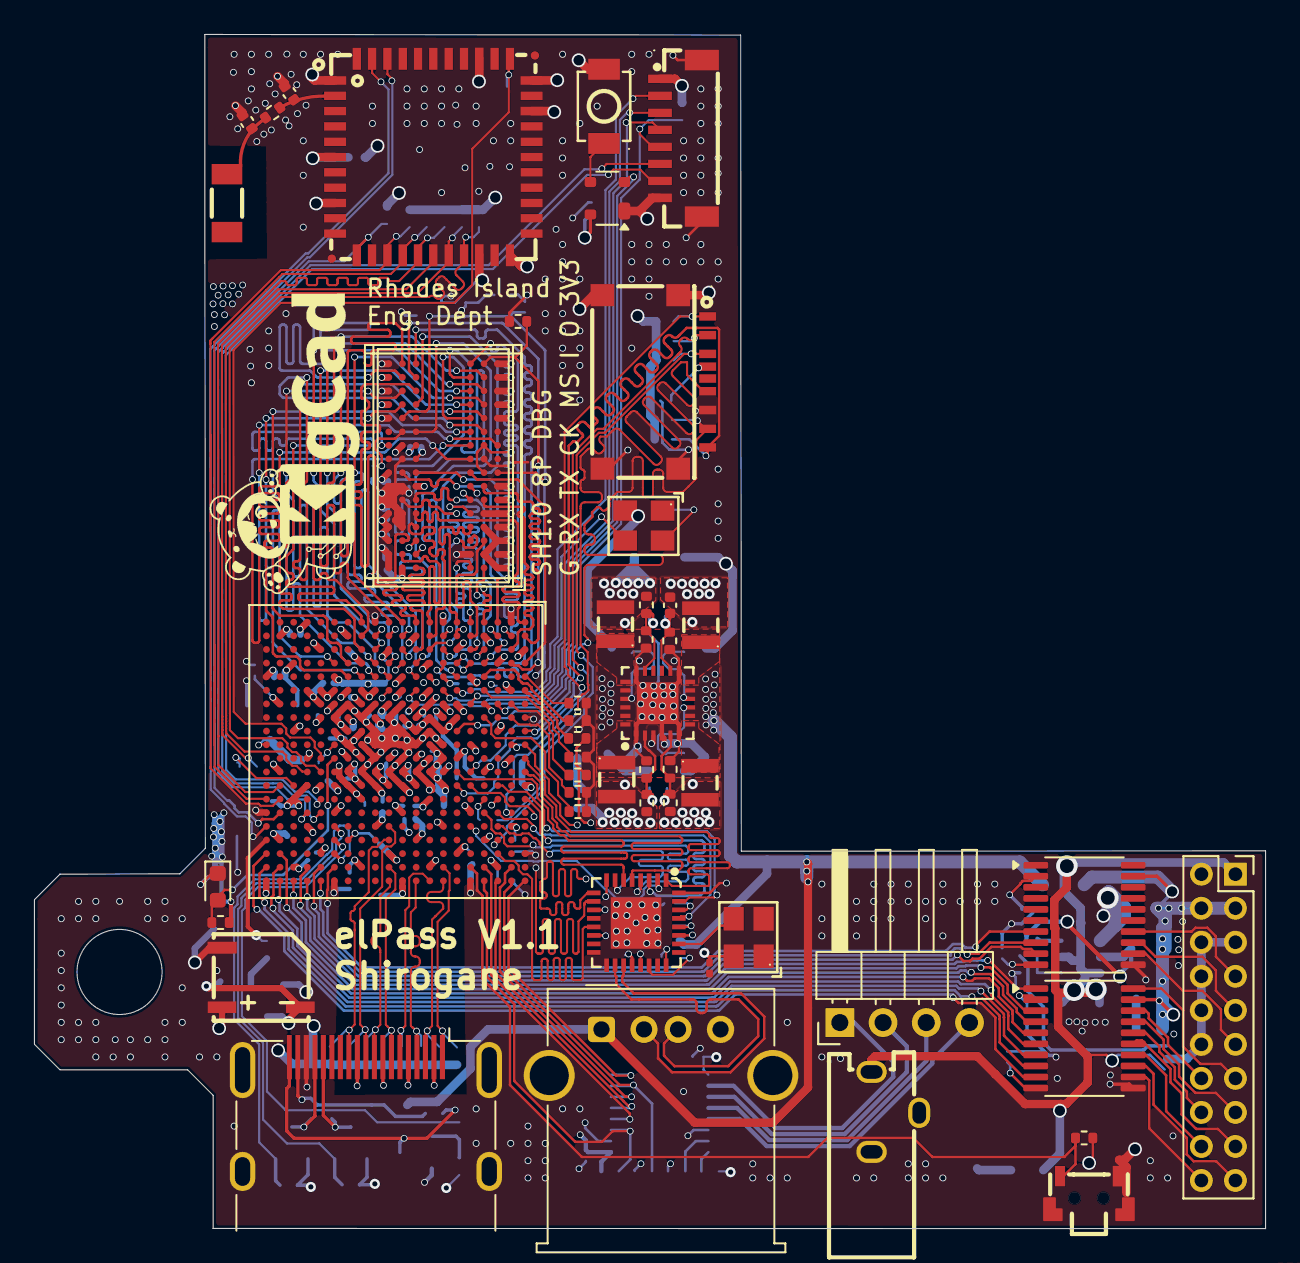
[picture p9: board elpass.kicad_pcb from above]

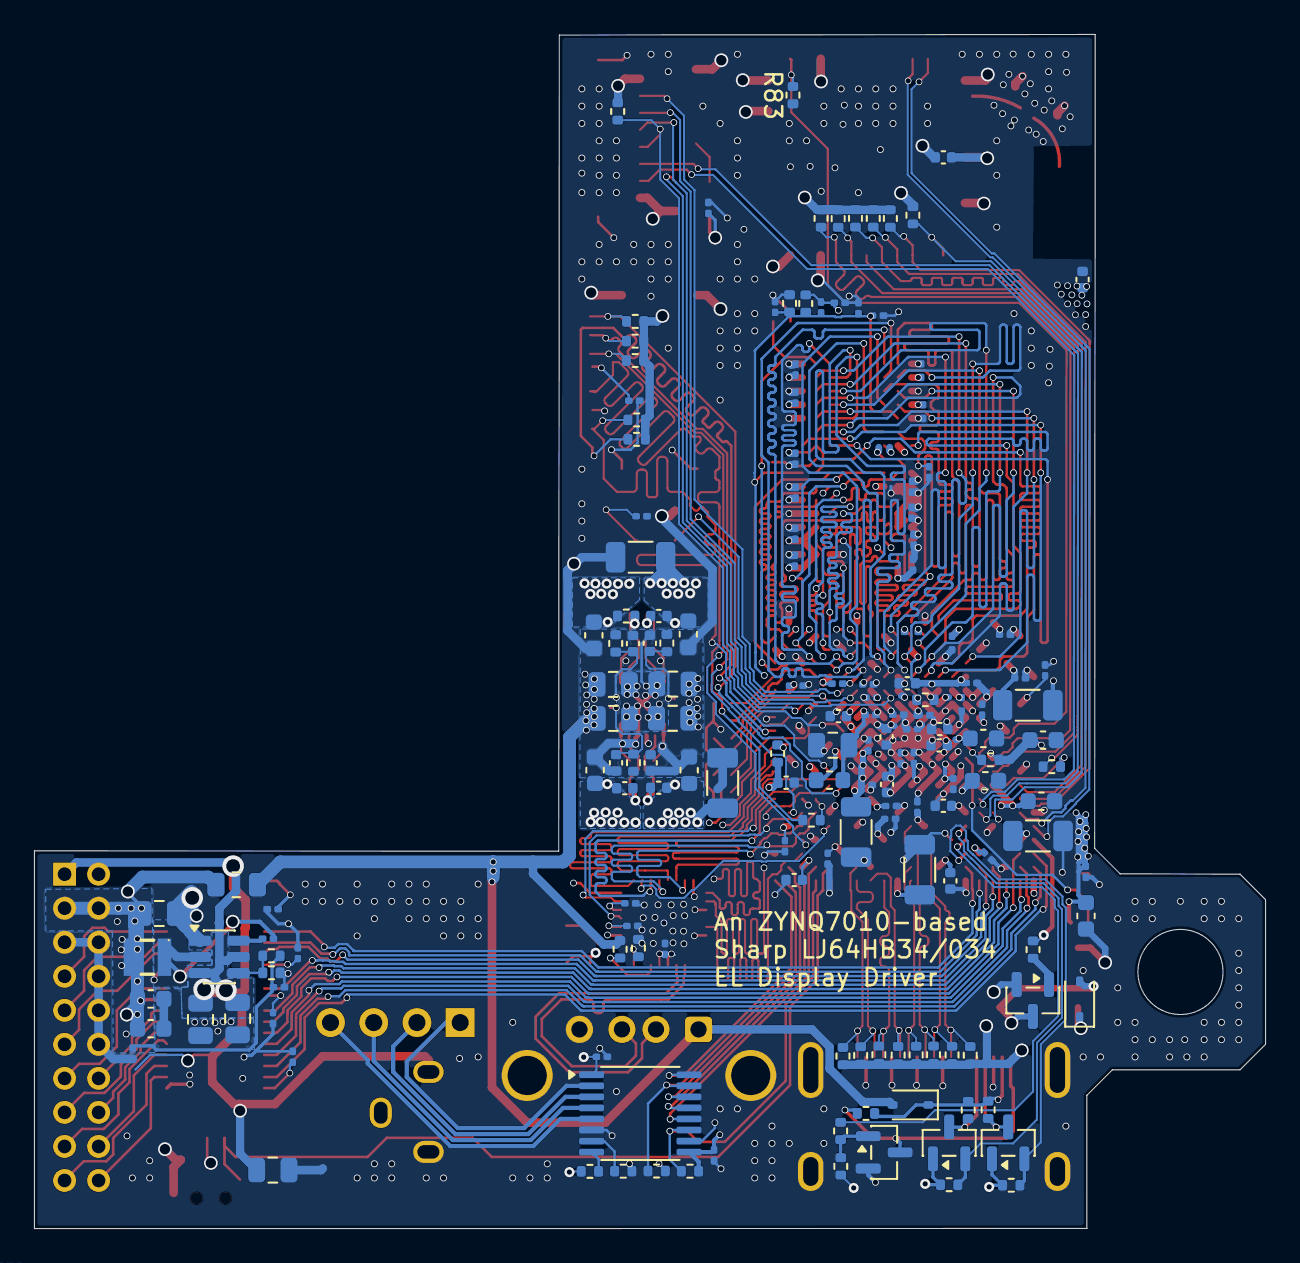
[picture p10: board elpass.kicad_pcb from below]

Board: 4 copper layers, 72.4 x 70.2 mm, 213 parts (165 on the bottom side), 186 nets.

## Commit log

2026-06-30 V1 initial release.
    [elpass.kicad_pcb, elpass.kicad_sch, power.kicad_sch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]
2026-09-13 some fixes
    [elpass.kicad_pcb, power.kicad_sch, zynq_pl_34.kicad_sch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]
